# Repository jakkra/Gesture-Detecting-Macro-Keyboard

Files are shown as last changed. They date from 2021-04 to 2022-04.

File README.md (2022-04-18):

# Gesture detection
tldr; Glorified Bluetooth macro keyboard with machine learning (TensorFlow Lite for Microcontrollers) running on an ESP32.
## Main features
- Capacitive touch pad for drawing gestures on that maps to actions on the computer.
- Capacitive touch bar for volume control.
- 11 Buttons for generic control.
- Optional AutoHotkey for programatical control exactly what shall happen when keys are pressed or a gesture is drawn.
- Small OLED display for various info such as crypto prices, remote Bluetooth status, local IP and gesture prediction debug info.
- BLE HID to connect to a computer and act as a keyboard.
- Such very RGB.

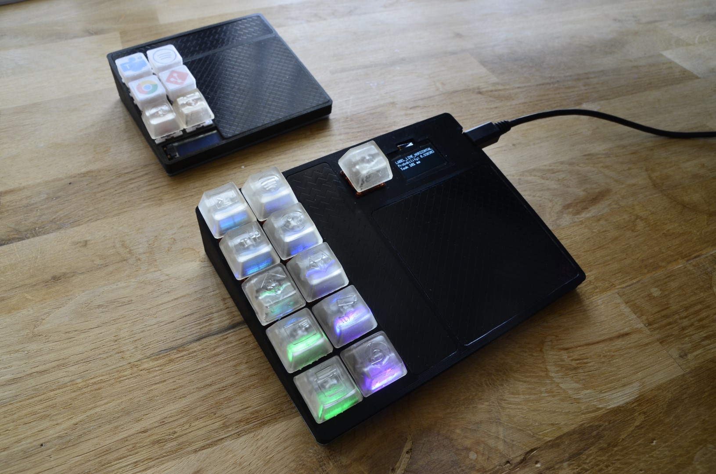
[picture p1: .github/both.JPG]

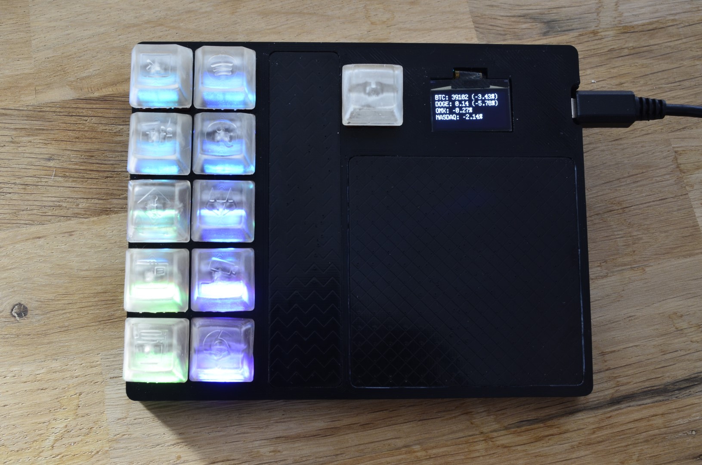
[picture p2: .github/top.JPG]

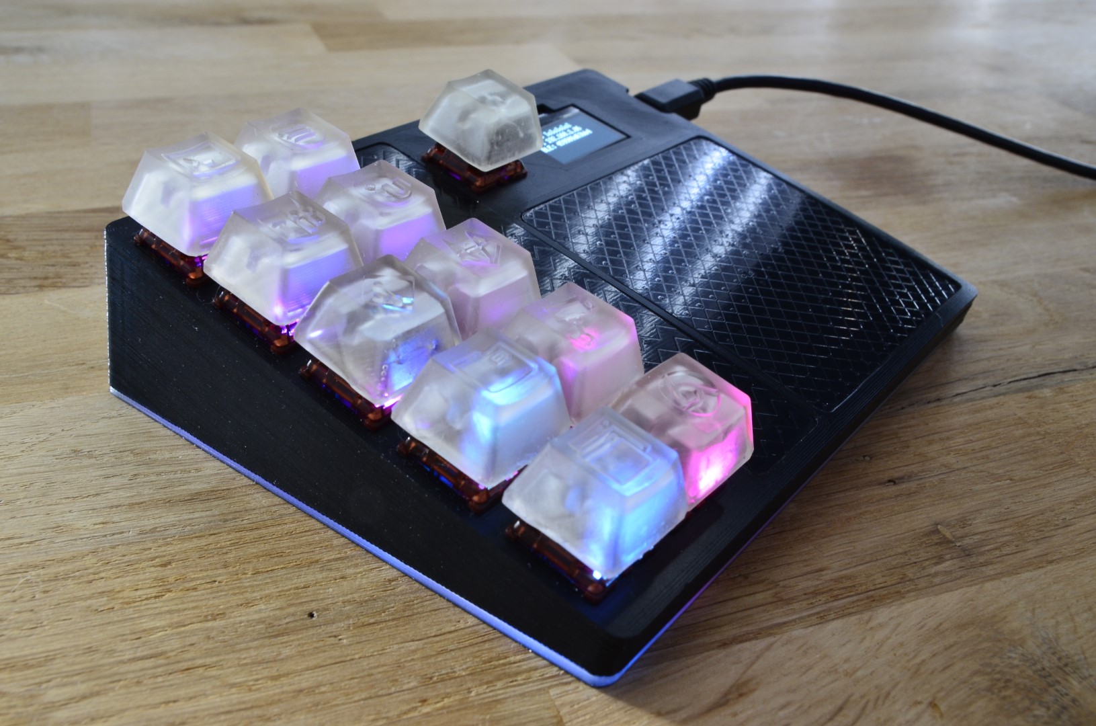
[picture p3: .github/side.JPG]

<p float="left">
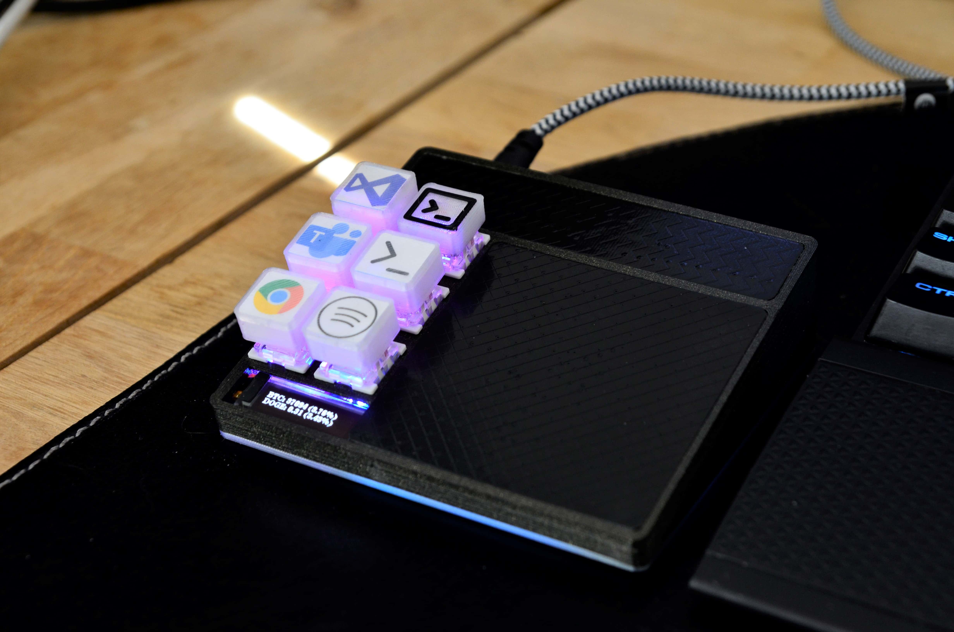
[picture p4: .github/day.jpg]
  
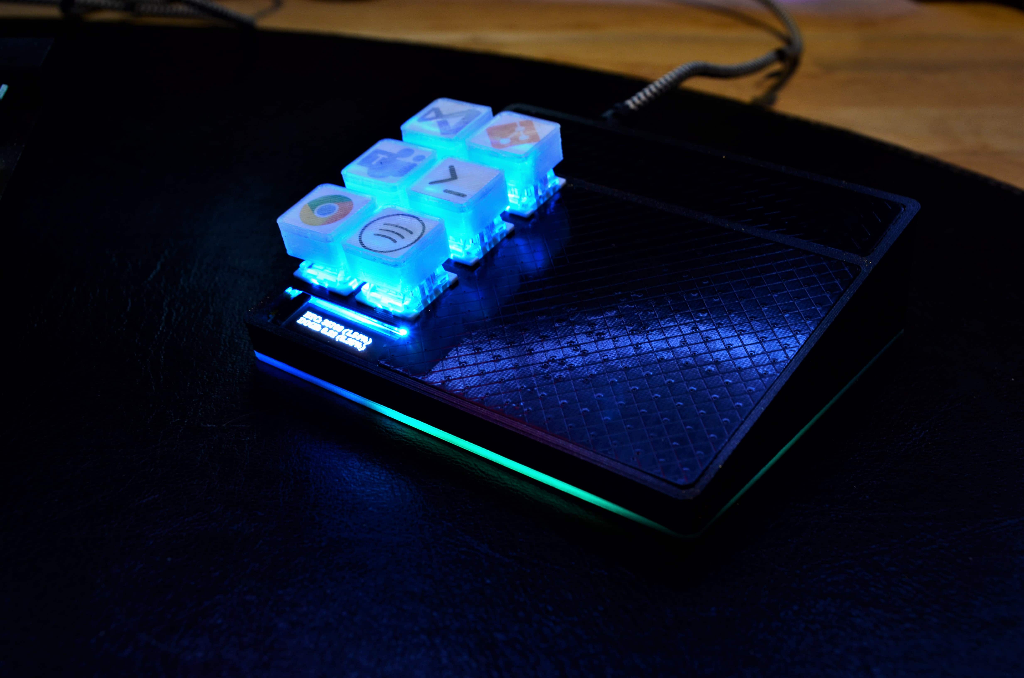
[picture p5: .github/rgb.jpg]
  
</p>

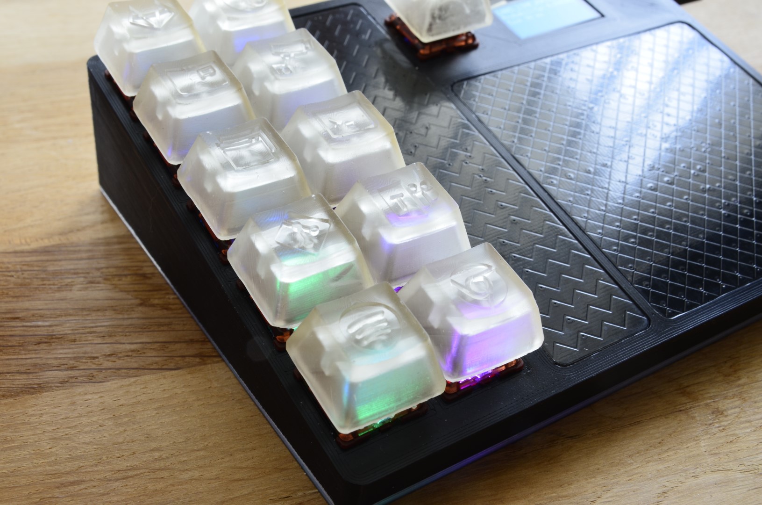
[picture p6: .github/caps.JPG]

training

### How it works
The switch presses and the touchpad gestures will end up being sent as a keyboard shortcut. This CAN be enough for some use cases, but it gets really powerful when coupled together with something AutoHotkey scripts running on the computer.

**Current AutoHotkey script works as following**

On the computer focus one window and then hold down one of SWITCH_1-10 for 2s. This will connect this key to that specific window. When clicking the key it will focus window if not in focus, and if in focus minimize it.

**Gestures are mapped as following**
| Gesture | Action | How to remember
| --- |:---|:---|
|ARROW_RIGHT | Media key next track | > as in next
|ARROW_UP | git push current branch | ʌ as in away/push
|C_GESTURE | Display all the COM ports on the computer as a notification | 'C' as in COM Port
|LINE_DOWN_GESTURE | git log | 'l' as in log
|LINE_HORIZONTAL_GESTURE | git diff | 
|S_GESTURE | git status | 'S' as in status
|ARROW_DOWN | git fetch and git pull current branch | 'V' as in pull
|... | whatever | ...

Note the commands involving git above will also focus the git terminal window before executing the action. For this to work SWITCH_2 is expected to be mapped with a git terminal window. For more detailed info about the actions look in 
[`hotkeys/hotkey_handler.ahk`](hotkeys/hotkey_handler.ahk)

#### SWITCH_11
Is special key and used for enable Bluetooth pairing (hold down for 5s) and moving through the different "menus" on the OLED screen.

## Compiling ESP32 code
Follow instruction on [https://github.com/espressif/esp-idf](https://github.com/espressif/esp-idf) to set up the esp-idf, then just run `idf.py build` or use the [VSCode extension](https://github.com/espressif/vscode-esp-idf-extension). Tested with esp-idf 4.2.

## Tensorflow gesture/shape detection
Tensorflow Lite is used to recognize what is being drawn on the touchpad. There are already some shapes/gestures training data collected by me and is found in the `/training/train_data` folder and a pre trained model using those is what is being used by default. The trackpad outputs x, y coordinates in the range [0,1792], coordinates collected between touch start and touch release are then converted into a 28x28 2D matrix which is used as input to TensorFlow.

**Example how simple it is to add a new gesture**
training
[Higher res video here](https://youtu.be/cg1-SUCJ2Vs)

### Gather train data
First you need to enter training mode on the macro keybord by holding down SWITCH_11 while plugging in power. In training mode the device pretty much just pipes the raw data from the trackpad over UART as a string with this format: `[x1, y1, x2, y2,...]\n`. Then go to the  `/training` folder. For each new gesture `collect_train_data.py` needs to run twice, first to collect train data and then to collect test data. For current number of gestures (7) about 150 train samples and about 45 test samples seems to be enough to get very good predictions.

    python collect_train_data.py --port COMX --gesture_name v_shape
    python collect_train_data.py --port COMX --gesture_name v_shape --test_data

After each drawn gesture a plot of the input data will be shown, if it looks bad because you made a misstake, then just press ENTER in the console and the last sample will be removed from the data. Press `ctrl+c` when done.

### Training the model
When collection of data is finished run `python train_model.py --center_gesture` it will take about 30s depending on computer. It will pick up all train data in the `train_data` folder, so remove any data for unwanted gestures. This script will generate a `gesture_model_tflite.c` and `gesture_model_tflite.h` files containing the TF Lite model that can be imported by embedded TF Lite. The `gesture_model_tflite.h` file is also generated from the Python code and contains various information such as the map between predictions (int) and their meaning, if `--center_gesture` was used when training, etc. All output from the `train_model.py` will be put in a folder `training/output`. When compiling the embedded code the generated `.c` and `.h` files are automatically copied into the C code directory so latest model will always be compiled.

#### `--center_gesture`
Option to center the gesture in the input matrix, this will help when the training data is drawn at a specific location on the trackpad, but you want it to be recognized anywhere. This option will remove functionality to have for example two line down gestures, one at the right side and one at the left side of the trackpad as this option will move both gestures to the center. For this to work the same change is needed on target before inputing the drawn gesture to the embedded model. This is handled automatically as this is added into the `gesture_model_tflite.h` file and handled accordingly in embedded code.

**Study the graphs to see how well the model performed on test data.**
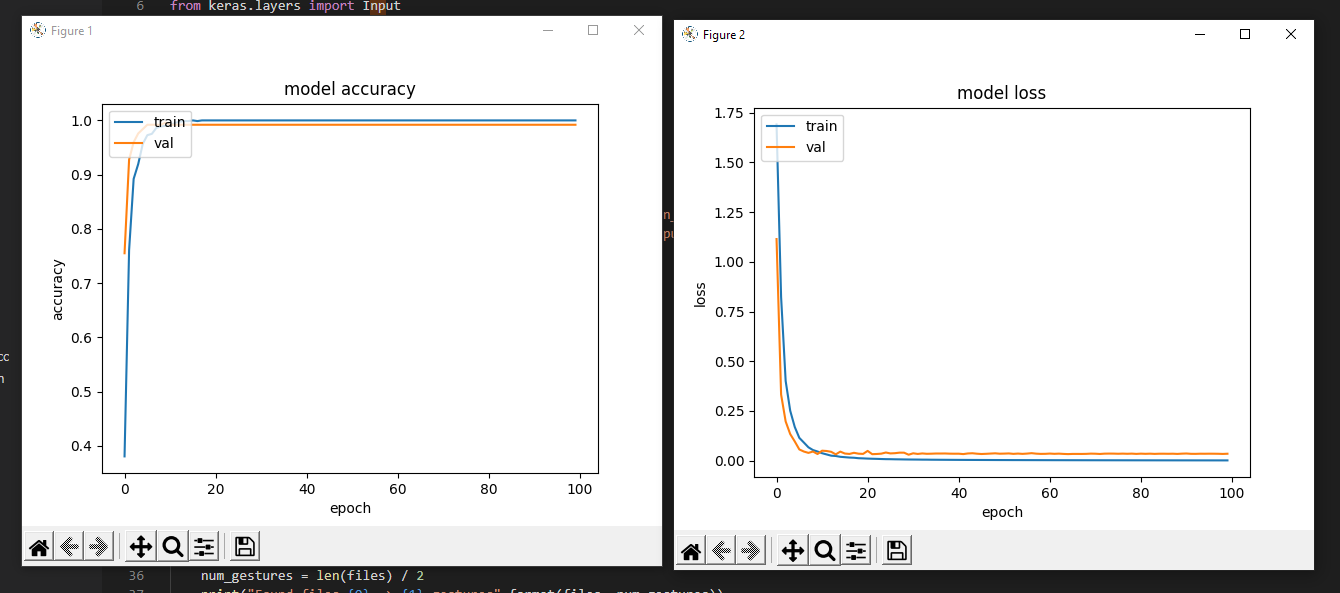
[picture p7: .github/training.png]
training


### Testing/verifying the model
Before moving the model into the microcontroller it's a good idea to test it first. First make sure the device is in training mode as described before, then test the model by running `python test_model.py --port COMX --center_gesture` and watch the predictions show as you draw on the trackpad.

## AutoHotkey setup
- Install Auto Hotkey from https://www.autohotkey.com/
- Right click on the `hotkeys/hotkey_handler.ahk` -> compile
- Now you will get an .exe file, right click on this and create a shortcut
- To auto start with Windows type `Windows key + r`
- Run `shell:startup` and paste the `hotkey_handler.exe - Shortcut` into the opened folder.
- Done

## CAD model
Full Fusion 360 project is found in `CAD` folder.

## Trill sensors
Bought from their Kickstarter in 2019, but can be bought today from [here now](https://bela.io/products/trill/)

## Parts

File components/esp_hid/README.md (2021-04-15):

## HID
Very inspired by https://github.com/espressif/esp-idf/tree/master/examples/bluetooth/bluedroid/ble/ble_hid_device_demo.

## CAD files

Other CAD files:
CAD/case.f3z

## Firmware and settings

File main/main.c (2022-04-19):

#include <string.h>
#include "esp_system.h"
#include "freertos/FreeRTOS.h"
#include "freertos/task.h"
#include "freertos/timers.h"
#include "esp_timer.h"
#include "esp_err.h"
#include "esp_log.h"
#include "nvs_flash.h"
#include <driver/i2c.h>
#include "tf_gesture_predictor.h"
#include "touchpad_sensor.h"
#include "ble_hid.h"
#include "hid_dev.h"
#include "keymap_config.h"
#include "hid_dev.h"
#include "menu.h"
#include "keypress_input.h"
#include "esp_wifi.h"
#include "esp_event.h"
#include "lwip/err.h"
#include "lwip/sys.h"
#include "market_data.h"
#include "key_backlight.h"
#include "sdkconfig.h"

#include "v.h"

#define I2C_PORT I2C_NUM_0

#define PRINT_GESTURE_DATA    0
#define SWITCH_UPDATE_RATE_MS 20
#define MARKET_DATA_REFRESH_INTERVAL_MS 60 * 1000

static const char* TAG = "main";

static void sendKeysFromGesture(gesture_label_t prediction);
static void touch_bar_event_callback(touch_bar_state state, int16_t raw_value);
static void keys_scanned_callback(key_info_t* keys, int number_of_keys);
static void init_wifi(void);
static void wifi_event_handler(void* arg, esp_event_base_t event_base, int32_t event_id, void* event_data);
static void periodic_update_thread(void* arg);
static void ble_hid_connection_callback(ble_hid_connection event, esp_bd_addr_t* addr);
static void runPrintTrainData(void);
static void disable_pairing_cb(TimerHandle_t xTimer);


static bool wifi_connected;
static esp_ip4_addr_t ip_addr;
static esp_bd_addr_t connected_ble_addr;
static  TimerHandle_t pairing_timer;

void app_main(void) {
  esp_err_t ret;
  float* in_matrix;
  gesture_prediction_t prediction;
  i2c_config_t i2c_config;

  ret = nvs_flash_init();
  if (ret == ESP_ERR_NVS_NO_FREE_PAGES || ret == ESP_ERR_NVS_NEW_VERSION_FOUND) {
    ESP_ERROR_CHECK(nvs_flash_erase());
    ret = nvs_flash_init();
  }
  ESP_ERROR_CHECK(ret);

  key_backlight_init();
  keypress_input_init(SWITCH_UPDATE_RATE_MS);

  i2c_config.mode = I2C_MODE_MASTER;
  i2c_config.sda_io_num = CONFIG_I2C_SDA_PIN;
  i2c_config.sda_pullup_en = GPIO_PULLUP_ENABLE;
  i2c_config.scl_io_num = CONFIG_I2C_SCL_PIN;
  i2c_config.scl_pullup_en = GPIO_PULLUP_ENABLE;
  i2c_config.master.clk_speed = 100000;

  ESP_ERROR_CHECK(i2c_param_config(I2C_NUM_0, &i2c_config));
  ESP_ERROR_CHECK(i2c_driver_install(I2C_NUM_0, I2C_MODE_MASTER, 0, 0, 0));

  ret = ESP_FAIL;
  for (int retries = 0; retries < 5 && ret != ESP_OK; retries++) {
    ret = touch_sensors_init(I2C_PORT, &touch_bar_event_callback);
  }

  // Holding SWITCH_MODE down when booting => enter training mode.
  if (keypress_input_read(KEYPAD_SWITCH_MODE)) {
      printf("Entering training mode\n");
      runPrintTrainData();
      // Never returns
      assert(false);
  }

  menu_init(I2C_PORT, CONFIG_I2C_SDA_PIN, CONFIG_I2C_SCL_PIN, CONFIG_OLED_RST_PIN);

  ble_hid_init(ble_hid_connection_callback);
  pairing_timer = xTimerCreate("BLE Pair Timeout", pdMS_TO_TICKS(30000), pdFALSE, (void*)0, disable_pairing_cb);
  init_wifi();

  ESP_ERROR_CHECK(tf_gesture_predictor_init());

  int64_t start = esp_timer_get_time();
  xTaskCreate(periodic_update_thread, "periodic_update_thread", 5000, NULL, 10, NULL);
  tf_gesture_predictor_run(v_shape, sizeof(v_shape), &prediction, PRINT_GESTURE_DATA);
  printf("Prediction took %dms\n", (int)(esp_timer_get_time() - start) / 1000);

  keypress_input_set_callback(keys_scanned_callback);

  while (true) {
    in_matrix = touch_sensors_touchpad_fetch();
    if (in_matrix) {
      tf_gesture_predictor_run(in_matrix, 28 * 28 * sizeof(float), &prediction, PRINT_GESTURE_DATA);

      if (prediction.probability > 0.95f) {
        sendKeysFromGesture(prediction.label);
      }
      menu_draw_gestures(&prediction);
      printf("Prediction: %s, prob: %f\n", getNameOfPrediction(prediction.label),  prediction.probability);
    } else {
      vTaskDelay(pdMS_TO_TICKS(10));
    }
  }
}

static void runPrintTrainData(void) {
  while (true) {
    if (!touch_sensors_touchpad_print_raw()) {
      vTaskDelay(pdMS_TO_TICKS(10));
    }
  }
}

static void sendKeysFromGesture(gesture_label_t prediction)
{
  esp_err_t err;
  key_mask_t key_mask;
  uint8_t num_keys;
  uint8_t keys[GESTURE_MAP_MAX_KEYS];

  err = keymap_config_gesture_get_keys(prediction, &key_mask, keys, &num_keys);
  if (err) {
    return;
  }
  if (ble_hid_request_access(50) == ESP_OK) {
    ble_hid_send_key(key_mask, keys, num_keys);
    vTaskDelay(pdMS_TO_TICKS(20));
    ble_hid_send_key(0, NULL, 0);
    ble_hid_give_access();
  }
}

static void touch_bar_event_callback(touch_bar_state state, int16_t raw_value)
{
  consumer_cmd_t key = 0;

  switch (state) {
    case TOUCH_BAR_TOUCH_START:
    case TOUCH_BAR_TOUCHED_IDLE:
    case TOUCH_BAR_TOUCH_END:
      break;
    case TOUCH_BAR_MOVING_UP:
      key = HID_CONSUMER_VOLUME_UP;
      break;
    case TOUCH_BAR_MOVING_DOWN:
      key = HID_CONSUMER_VOLUME_DOWN;
      break;
    default:
      break;
      ESP_LOGE(TAG, "Unknown touch bar state %d", state);
  }
  if (key != 0) {
    if (ble_hid_request_access(50) == ESP_OK) {
      ble_hid_send_consumer_key(key, true);
      ble_hid_send_consumer_key(key, false);
      ble_hid_give_access();
    }
  }
}

static void disable_pairing_cb(TimerHandle_t xTimer)
{
  ble_hid_set_pairable(false);
  key_backlight_set_mode(KEY_BACKLIGHT_RAINBOW);
  menu_set_page(PAGE_GESTURE);
  ESP_LOGD(TAG, "Disabled pairing after timeout");
}

static char* keypad_switch_to_name(keypad_switch_t switch_num)
{
  switch (switch_num) {
    case KEYPAD_SWITCH_1:
      return "KEYPAD_SWITCH_1";
    case KEYPAD_SWITCH_2:
      return "KEYPAD_SWITCH_2";
    case KEYPAD_SWITCH_3:
      return "KEYPAD_SWITCH_3";
    case KEYPAD_SWITCH_4:
      return "KEYPAD_SWITCH_4";
    case KEYPAD_SWITCH_5:
      return "KEYPAD_SWITCH_5";
    case KEYPAD_SWITCH_6:
      return "KEYPAD_SWITCH_6";
    case KEYPAD_SWITCH_7:
      return "KEYPAD_SWITCH_7";
    case KEYPAD_SWITCH_8:
      return "KEYPAD_SWITCH_8";
    case KEYPAD_SWITCH_9:
      return "KEYPAD_SWITCH_9";
    case KEYPAD_SWITCH_10:
      return "KEYPAD_SWITCH_10";
    case KEYPAD_SWITCH_MODE:
      return "KEYPAD_SWITCH_MODE";
    default:
      return "INVALID_SWITCH";
  }
}

static void keys_scanned_callback(key_info_t* switches, int number_of_keys)
{
  esp_err_t err = ESP_FAIL;
  key_mask_t key_mask;
  bool longpress;
  uint8_t num_keys;
  uint8_t keys[GESTURE_MAP_MAX_KEYS];

  for (int i = 0; i < number_of_keys; i++) {
    if (((switches[i].state != KEYPAD_SWITCH_STATE_LONG_PRESSED) && (switches[i].state != KEYPAD_SWITCH_STATE_SHORT_PRESSED))) {
      continue;
    }

    longpress = switches[i].state == KEYPAD_SWITCH_STATE_LONG_PRESSED;

    printf("%s %d => longpress: %d\n", keypad_switch_to_name(switches[i].key), switches[i].state, longpress);

    switch (switches[i].key) {
      case KEYPAD_SWITCH_1:
      case KEYPAD_SWITCH_2:
      case KEYPAD_SWITCH_3:
      case KEYPAD_SWITCH_4:
      case KEYPAD_SWITCH_5:
      case KEYPAD_SWITCH_6:
      case KEYPAD_SWITCH_7:
      case KEYPAD_SWITCH_8:
      case KEYPAD_SWITCH_9:
      case KEYPAD_SWITCH_10:
        err = keymap_config_switch_get_keys(switches[i].key, longpress, &key_mask, keys, &num_keys);
        break;
      case KEYPAD_SWITCH_MODE:
        if (!longpress) {
          menu_next_page();
        } else {
          xTimerStop(pairing_timer, portMAX_DELAY);
          xTimerStart(pairing_timer, portMAX_DELAY);
          ble_hid_set_pairable(true);
          menu_set_page(PAGE_PAIRING);
          key_backlight_set_mode(KEY_BACKLIGHT_BLINKING);
          ESP_LOGI(TAG, "BLE pairing enabled for 30s");
        }
        break;
      default:
        return;
    }

    if (err == ESP_OK) {
      if (ble_hid_request_access(250) == ESP_OK) {
        ble_hid_send_key(key_mask, keys, num_keys);
        vTaskDelay(pdMS_TO_TICKS(30));
        ble_hid_send_key(0, NULL, 0);
        ble_hid_give_access();
      }
    }
  }
}

static void init_wifi(void)
{
    ESP_ERROR_CHECK(esp_netif_init());

    ESP_ERROR_CHECK(esp_event_loop_create_default());
    esp_netif_create_default_wifi_sta();

    wifi_init_config_t cfg = WIFI_INIT_CONFIG_DEFAULT();
    ESP_ERROR_CHECK(esp_wifi_init(&cfg));

    ESP_ERROR_CHECK(esp_event_handler_register(WIFI_EVENT, ESP_EVENT_ANY_ID, &wifi_event_handler, NULL));
    ESP_ERROR_CHECK(esp_event_handler_register(IP_EVENT,  IP_EVENT_STA_GOT_IP, &wifi_event_handler, NULL));

    wifi_config_t wifi_config = {
        .sta = {
            .ssid = CONFIG_ESP_WIFI_SSID,
            .password = CONFIG_ESP_WIFI_PASSWORD,
        },
    };
    ESP_ERROR_CHECK(esp_wifi_set_mode(WIFI_MODE_STA) );
    ESP_ERROR_CHECK(esp_wifi_set_config(ESP_IF_WIFI_STA, &wifi_config) );
    ESP_ERROR_CHECK(esp_wifi_start() );

    ESP_LOGI(TAG, "WiFi Started");
}

static void refresh_menu_connection_data(void) {
  char ip[50];
  char addr[50];
  memset(ip, 0, sizeof(ip));
  memset(addr, 0, sizeof(addr));
  snprintf(ip, sizeof(ip), IPSTR, IP2STR(&ip_addr));

  snprintf(addr, sizeof(addr), "%08x%04x",\
                (connected_ble_addr[0] << 24) + (connected_ble_addr[1] << 16) + (connected_ble_addr[2] << 8) + connected_ble_addr[3],
                (connected_ble_addr[4] << 8) + connected_ble_addr[5]);
  menu_draw_connection_status(CONFIG_ESP_WIFI_SSID, wifi_connected, ip, addr);
}

static void wifi_event_handler(void* arg, esp_event_base_t event_base, int32_t event_id, void* event_data)
{
    if (event_base == WIFI_EVENT && event_id == WIFI_EVENT_STA_START) {
        esp_wifi_connect();
    } else if (event_base == WIFI_EVENT && event_id == WIFI_EVENT_STA_DISCONNECTED) {
        ESP_LOGI(TAG, "Failed to connect WiFi");
        wifi_connected = false;
        memset(&ip_addr, 0, sizeof(ip_addr));
        refresh_menu_connection_data();
        esp_wifi_connect();
    } else if (event_base == IP_EVENT && event_id == IP_EVENT_STA_GOT_IP) {
        ip_event_got_ip_t* event = (ip_event_got_ip_t*) event_data;
        ESP_LOGI(TAG, "got ip:" IPSTR, IP2STR(&event->ip_info.ip));
        wifi_connected = true;
        ip_addr = event->ip_info.ip;
        refresh_menu_connection_data();
    }
}

static void periodic_update_thread(void* arg) {
  double btc, doge, omx = 0, nasdaq, btc_change, doge_change, omx_change = 0, nasdaq_change;
  for (;;) {
    if (wifi_connected) {
      market_data_get_crypto("bitcoin", &btc, &btc_change);
      market_data_get_crypto("dogecoin", &doge, &doge_change);
      market_data_get_stock("^OMX", &omx, &omx_change);
      market_data_get_stock("^IXIC", &nasdaq, &nasdaq_change);
      menu_draw_market_data(btc, btc_change, doge, doge_change, omx, omx_change, nasdaq, nasdaq_change);
      vTaskDelay(pdMS_TO_TICKS(MARKET_DATA_REFRESH_INTERVAL_MS));
    } else {
      vTaskDelay(pdMS_TO_TICKS(2000));
    }
  }
}

static void ble_hid_connection_callback(ble_hid_connection event, esp_bd_addr_t* addr) {
  switch (event) {
    case BLE_HID_CONNECTED:
      memcpy(connected_ble_addr, addr, sizeof(esp_bd_addr_t));
      refresh_menu_connection_data();
      break;
    case BLE_HID_DISCONNECTED:
      memset(connected_ble_addr, 0, sizeof(esp_bd_addr_t));
      refresh_menu_connection_data();
      break;
    case BLE_HID_BOND_SUCCESS:
      xTimerStop(pairing_timer, portMAX_DELAY);
      ble_hid_set_pairable(false);
      key_backlight_set_mode(KEY_BACKLIGHT_RAINBOW);
      menu_set_page(PAGE_GESTURE);
      break;
    default:
      break;
  }
}

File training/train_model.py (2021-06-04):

import tensorflow as tf
import numpy as np
from tensorflow.keras.utils import to_categorical
from keras.models import Sequential
from keras.layers import Input
from keras.layers import Conv2D
from keras.layers import MaxPooling2D
from keras.layers import Dense
from keras.layers import Flatten
from keras.optimizers import SGD

from matplotlib import pyplot as plt
import os
from pathlib import Path
import argparse
import training_utils

train_dir = os.path.dirname(os.path.realpath(__file__)) + "/train_data/"
output_dir = os.path.dirname(os.path.realpath(__file__)) + "/output/"


def create_img_from_line(line, center_gesture):
	line = line.replace(' ', '')
	line = line.replace('\'', '')
	line = line.replace('[', '')
	line = line.replace(']', '')
	line = line.replace('\n', '')
	line = line.split(',')
	img = np.zeros((28, 28))
	for i in range(0, len(line), 2):
		img[max(0, (int(line[i + 1]) - 1)//64), max(0, (int(line[i])//64) - 1)] = 1
	
	# Option to center the gesture in the matrix, this will help when the training data is drawn 
	# at a specific location on the trackpad. However this will remove functionality to have for example
	# two line down gestures, one at the right side and one at the left side of the trackpad as this
	# function will move it to the center.
	# For this to work the same change is needed on target before inputing the drawn gesture
	# to the embedded model.
	if center_gesture:
		img = training_utils.moveToCenter(img)
	
	img = img.reshape(1, 28, 28, 1)
	img = img.astype('float32')
	return img

def load_manual_dataset(center_gesture):
	files = os.listdir(train_dir)
	num_gestures = len(files) / 2
	print("Found files {0} => {1} gestures".format(files, num_gestures))
	trainX = []
	testX = []
	trainY = []
	testY = []
	file_index = 0
	gestures = {}

	# Assumes the train/test data folder is not modified by user.
	# It should be generated using collect_train_data.py
	for file_name in files:
		gesture_name = file_name.split('.')[0]
		if (gesture_name not in gestures):
			gestures[gesture_name] = len(gestures)

		gesture_id = gestures[gesture_name]

		if (file_name.endswith('.train')):
			train_file = open(train_dir + file_name, "r")
			train_lines = train_file.readlines()

			for line in train_lines:
				trainX.append(create_img_from_line(line, center_gesture))
				trainY.append(gesture_id)

		elif file_name.endswith('.test'):
			test_file = open(train_dir + file_name, "r")
			test_lines = test_file.readlines()

			for line in test_lines:
				testX.append(create_img_from_line(line, center_gesture))
				testY.append(gesture_id)
		
	trainX = np.array(trainX)
	trainY = np.array(trainY)
	testX = np.array(testX)
	testY = np.array(testY)

	trainX = trainX.reshape((trainX.shape[0], 28, 28, 1))
	testX = testX.reshape((testX.shape[0], 28, 28, 1))
	
	print('Done creating test and train matrices')
	print(len(testX), len(testY))
	print(len(trainX), len(trainY))
	print(gestures)

	trainY = to_categorical(trainY)
	testY = to_categorical(testY)
	return trainX, trainY, testX, testY, gestures

# define CNN model
def define_model(num_gestures):
	model = Sequential()
	model.add(Input(shape=(28, 28, 1)))
	model.add(Conv2D(8, (3, 3), activation='relu', kernel_initializer='he_uniform'))
	model.add(MaxPooling2D((2, 2)))
	model.add(Conv2D(16, (3, 3), activation='relu', kernel_initializer='he_uniform'))
	model.add(Conv2D(16, (3, 3), activation='relu', kernel_initializer='he_uniform'))
	model.add(MaxPooling2D((2, 2)))
	model.add(Flatten())
	model.add(Dense(16, activation='relu', kernel_initializer='he_uniform'))
	model.add(Dense(num_gestures, activation='softmax'))
	# compile model
	opt = SGD(lr=0.001, momentum=0.9) # TODO Experiment with lr if needed, does not look like it right now
	model.compile(optimizer=opt, loss='categorical_crossentropy', metrics=['accuracy'])
	return model
 
if __name__ == "__main__":
	parser = argparse.ArgumentParser(description='Create and store training data')
	parser.add_argument('--center_gesture', required=False, action='store_true', help='Move the drawn gesture to the center of the matrix. Need to match if model was trained with centered data or not.')
	
	args = parser.parse_args()
	# Create folder for the generated files
	Path(output_dir).mkdir(parents=True, exist_ok=True)
	print('create', output_dir)
	trainX, trainY, testX, testY, gesture_map = load_manual_dataset(args.center_gesture)
	print('Loaded train data shape is {0} and test data shape is {1}'.format(trainX.shape, testX.shape))

	# define model
	model = define_model(len(gesture_map))
	#model.load_weights('good_model_weights.h5')
	# fit model
	history = model.fit(trainX, trainY, epochs=80, batch_size=10, verbose=1, validation_data=(testX, testY))
	model.save_weights('good_model_weights.h5')

	plt.plot(history.history['accuracy'])
	plt.plot(history.history['val_accuracy'])
	plt.title('model accuracy')
	plt.ylabel('accuracy')
	plt.xlabel('epoch')
	plt.legend(['train', 'val'], loc='upper left')

	plt.figure()
	plt.plot(history.history['loss'])
	plt.plot(history.history['val_loss'])
	plt.title('model loss')
	plt.ylabel('loss')
	plt.xlabel('epoch')
	plt.legend(['train', 'val'], loc='upper left')
	plt.show()
	# save model
	model.save(output_dir + 'tf_gesture_model.h5')

	# Convert the model to Tensorflow Lite format.
	converter = tf.lite.TFLiteConverter.from_keras_model(model)
	tflite_model = converter.convert()

	# Save the model.
	with open(output_dir + 'gesture_model.tflite', 'wb') as f:
		f.write(tflite_model)
	
	# Convert to C++ file
	res = os.system("xxd -i {0}/gesture_model.tflite > {0}/gesture_model_tflite.cc".format(output_dir))

	# Rename the model, xxd gives it a name that contains the directory path also make the model const
	cppModelFileContentLines = []
	with open(output_dir + 'gesture_model_tflite.cc', 'r') as f:
		cppModelFileContentLines = f.readlines()
	os.remove(output_dir + 'gesture_model_tflite.cc') # Remove original c++ model
	cppModelFileContentLines[0] = 'const unsigned char gesture_model_tflite_data[] = {\n' # rename the large byte array containing the model
	cppModelFileContentLines.insert(0, '#include "gesture_model_tflite.h"\n')
	with open(output_dir + 'gesture_model_tflite.cc', 'w') as f: # create the fixed c++ model
		f.writelines(cppModelFileContentLines)
	
	# Create header file to access generated model
	# Append to the header file the map between TF result and the actual gesture
	with open(output_dir + 'gesture_model_tflite.h', 'w') as f:
		f.write('/*\nThis is a automatically generated TensorFlow Lite model by train_model.py, see README.md for more info.\nIt is converted into a C data array using xxd and is defined in gesture_model_tflite.cc\n*/\n')
		f.write('#ifndef TENSORFLOW_LITE_GESTURE_MODEL_H_\n')
		f.write('#define TENSORFLOW_LITE_GESTURE_MODEL_H_\n')

		# Add define so c code can automatically handle if model was trained with --center_gesture or not
		if (args.center_gesture):
			f.write('\n#define MODEL_CENTER_GESTURE_IN_DATA\n\n')
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

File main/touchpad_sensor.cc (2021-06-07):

#include "touchpad_sensor.h"
#include "Trill.h"
#include "driver/i2c.h"
#include <string.h>
#include "esp_log.h"

#define MAX(x, y) (((x) > (y)) ? (x) : (y))

// Input from Trill sensor is 1792 x 1792
#define MAX_TRILL_COORDINATE    1792
// That's a large matrix, to rounding it into a 28x28 matrix.
#define MAX_LOCAL_COORDINATE    28
#define DIVIDER_FACTOR          (MAX_TRILL_COORDINATE / MAX_LOCAL_COORDINATE) // 64

#define SAMPLE_DELAY 2
#define TRILL_BAR_READ_INTERVAL_MS 50
#define TRILL_BAR_MIN_INPUT_VAL 1408
#define TRILL_BAR_MIN_CHANGE 25

static const char* TAG = "touchpad_sensor";


static float input[MAX_LOCAL_COORDINATE][MAX_LOCAL_COORDINATE];
static Trill trillSquare;
static Trill trillBar;
static touch_bar_callback* bar_event_callback;
static i2c_port_t i2c_port;

esp_err_t touch_sensors_init(touch_bar_callback* touch_bar_callback);
float* touch_sensors_touchpad_fetch(void);
static void touch_bar_task(void* params);

esp_err_t touch_sensors_init(i2c_port_t port, touch_bar_callback* touch_bar_callback)
{
    int err;
    esp_err_t ret = ESP_OK;
    i2c_port = port;

    err = trillSquare.setup(Trill::TRILL_SQUARE, i2c_port);
    if (err) {
        ret = ESP_FAIL;
        ESP_LOGE(TAG, "Failed to init TRILL_SQUARE: %d", err);
    }
    err = trillBar.setup(Trill::TRILL_BAR, i2c_port);
    if (!err) {
        TaskHandle_t touch_task_handle;
        BaseType_t status = xTaskCreate(touch_bar_task, "touchbar_task", 2048, NULL, tskIDLE_PRIORITY, &touch_task_handle);
        assert(status == pdPASS);
    } else {
        ret = ESP_FAIL;
        ESP_LOGE(TAG, "Failed to init TRILL_BAR: %d", err);
    }
    bar_event_callback = touch_bar_callback;

    return ret == 0  ? ESP_OK : ESP_FAIL;
}

float* touch_sensors_touchpad_fetch(void)
{
    bool touchActive = false;
    uint16_t input_x;
    uint16_t input_y;
    uint8_t x;
    uint8_t y;

    while (true) {
        trillSquare.read();
        if (trillSquare.getNumTouches() > 0 && trillSquare.getNumHorizontalTouches() > 0) {
            if (!touchActive) {
                memset(input, 0, sizeof(input));
            }
            input_x = MAX_TRILL_COORDINATE - trillSquare.touchLocation(0);
            input_y = trillSquare.touchHorizontalLocation(0);
            x = MAX((input_x / DIVIDER_FACTOR) - 1, 0);
            y = MAX((input_y / DIVIDER_FACTOR) - 1, 0);
            input[x][y] = 1;

            touchActive = true;
        } else if(touchActive) {
            touchActive = false;
            return (float*)input;
        } else {
            return NULL;
        }
        vTaskDelay(pdMS_TO_TICKS(SAMPLE_DELAY));
    }

    return NULL;
}

bool touch_sensors_touchpad_print_raw(void)
{
    bool touchActive = false;

    while (true) {
        trillSquare.read();
        if (trillSquare.getNumTouches() > 0 && trillSquare.getNumHorizontalTouches() > 0) {
            if (!touchActive) {
                printf("START:");
            }
            printf("%d", trillSquare.touchHorizontalLocation(0));
            printf(",");

            printf("%d", MAX_TRILL_COORDINATE - trillSquare.touchLocation(0));
            printf(",");
            touchActive = true;
        } else if (touchActive) {
            // Print a single line when touch goes off
            touchActive = false;
            printf("\n");
            return true;
        } else {
            return false;
        }
        vTaskDelay(pdMS_TO_TICKS(SAMPLE_DELAY));
    }

    return false;
}

static void touch_bar_task(void* params)
{
    bool touchActive = false;
    int16_t input_val;
    int16_t prev_val;

    while (true) {
        trillBar.read();
        if (trillBar.getNumTouches() == 1) {
            input_val = MAX_TRILL_COORDINATE - trillBar.touchLocation(0);
            input_val = input_val + TRILL_BAR_MIN_INPUT_VAL; // Make input between 0 and max_input + min_input;
            if (!touchActive) {
                // Since sometimes if the Trill bar is dirty or similar it outputs random touches
                // This is to verify that there still is a touch after TRILL_BAR_READ_INTERVAL_MS
                bool check = true;
                int16_t prev_check_val = input_val;
                for (int i = 0; i < 10; i++) {
                    vTaskDelay(pdMS_TO_TICKS(TRILL_BAR_READ_INTERVAL_MS / 10));
                    trillBar.read();
                    if (trillBar.getNumTouches() == 0 || trillBar.touchLocation(0) == input_val) {
                        check = false;
                        break;
                    }
                }
                if (check) {
                    touchActive = true;
                    prev_val = input_val;
                }
                bar_event_callback(TOUCH_BAR_TOUCH_START, input_val);
            } else {
                if (abs(input_val - prev_val) > TRILL_BAR_MIN_CHANGE) {
                    if (input_val > prev_val) {
                        bar_event_callback(TOUCH_BAR_MOVING_UP, input_val);
                    } else {
                        bar_event_callback(TOUCH_BAR_MOVING_DOWN, input_val);
                    }
                } else {
                    bar_event_callback(TOUCH_BAR_TOUCHED_IDLE, input_val);
                }
            }

            prev_val = input_val;
        } else if (touchActive) {
            touchActive = false;
            bar_event_callback(TOUCH_BAR_TOUCH_END, input_val);
        }
        vTaskDelay(pdMS_TO_TICKS(TRILL_BAR_READ_INTERVAL_MS));
    }

}

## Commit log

2021-04-12 TensorFlow Lite running and correctly predicting on ESP32.
    [main.c]
2021-04-14 Fix print format.
2021-04-14 Add Trill sensor driver as submodule. Implement wrapper around it to get a gesture.
2021-04-15 Add BLE HID support and send keystrokes after detection of a gesture.
    [partitions_singleapp.csv]
2021-04-15 Generate c function for label(int) to its name. Some fixes in the generation of cpp model code.
    [main.c]
2021-05-05 Add led strip support for keycap backlight.
2021-05-05 WiFi support for fetching crypto data. New menu system for OLED => SWITCH_6 goes through the different screens.
    [partitions_singleapp.csv]
2021-05-13 Enter data collecting mode by holding SWITCH_6 at boot.
2021-05-13 Fix error in train data to matrix convertion.
    [collect_train_data.py]
2021-05-18 Only allow bonding with new devices when we pressed the pairing button and enabled pairing.
2021-05-23 Fix bug when writing training data to file. Add new gestures and update the trained model.
    [collect_train_data.py]
2021-06-04 Update README.
    [case.f3z]
2021-06-06 Create a minimal skdconfig.defaults.
    [partitions.csv]
2021-06-07 Fix --center_gesture argument requiring a value.
    [test_model.py]
2021-12-28 Use correct u8g2 method for setting I2C address.
    [display.c]
2021-12-28 Fix allocating wrong size.
    [menu.c]
2022-01-26 Version 2 support with more switches solderad as a matrix to save GPIO, separate mode button, larger display.
2022-04-02 Blink LEDs and display on display when in BLE pairing enabled mode.
2022-04-19 Fix for window switching when using multiple virtual desktops.
